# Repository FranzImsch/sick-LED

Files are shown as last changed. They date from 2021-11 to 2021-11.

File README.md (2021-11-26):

# Sick LED Driver

## [Schematic](https://franz.science/sick-LED/Schematic.pdf)
## [iBOM](https://franz.science/sick-LED/Hardware/KiCad-Files/bom/index.html)
  
**\*Work in progress\***

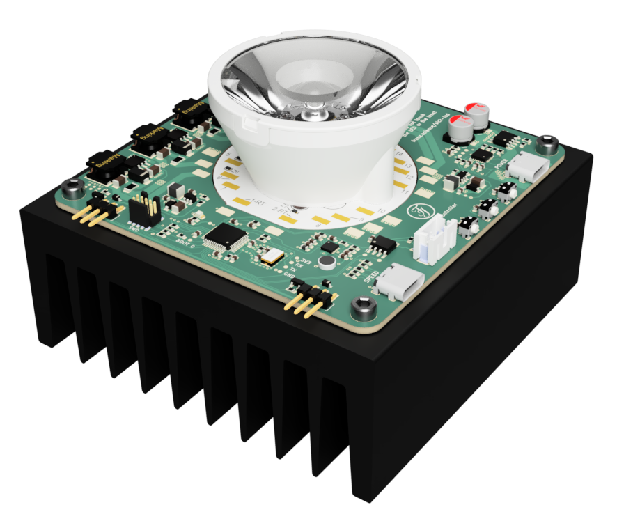
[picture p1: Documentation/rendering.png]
rendering


Six channel LED driver board that is built around the [LZ7-04-M2PD](https://www.osram.com/ecat/LED%20ENGIN%20LuxiGen%20LZ7-04M2PD/com/en/class_pim_web_catalog_103489/prd_pim_device_13582430/) on MCPCB from LED Engin.

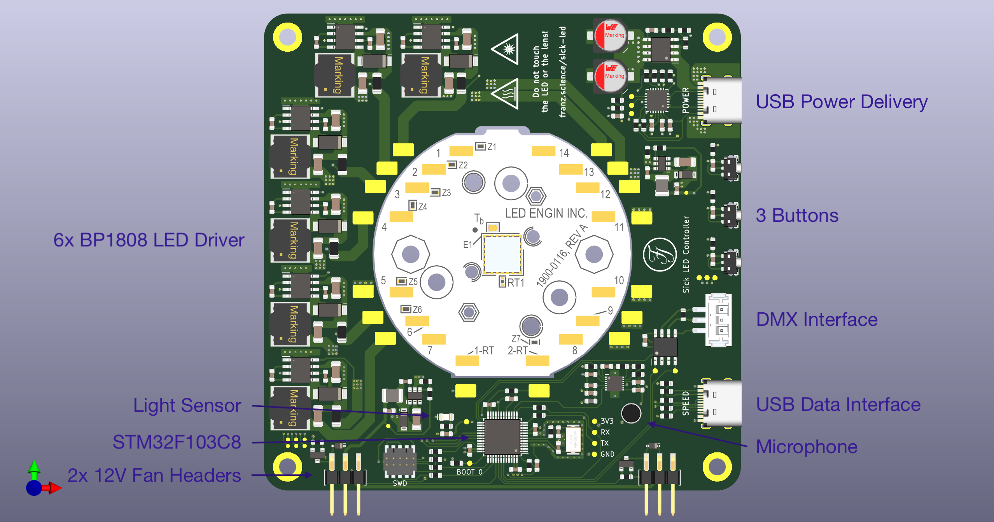
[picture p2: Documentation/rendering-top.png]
rendering

 It's a 60W LED with six colours, which can be used to do some adjustable white experiments due to the relatively full spectrum of the LED (at least compared to a normal RGB-LED): 

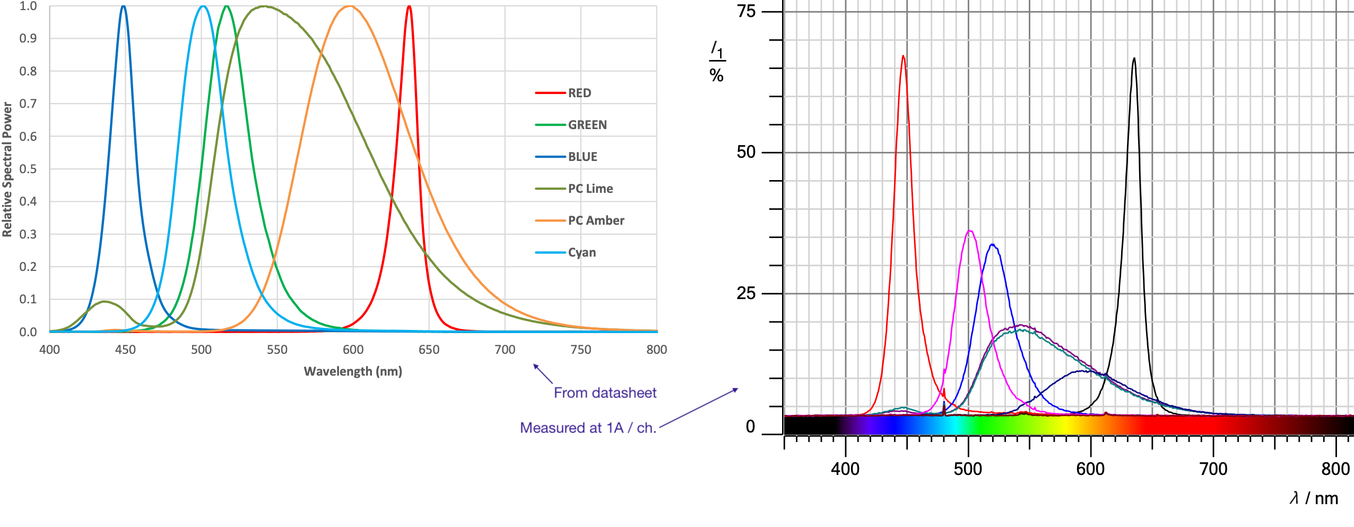
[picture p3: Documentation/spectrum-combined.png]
spectrum


The project's objective is not to build an LED that is as bright as possible but to create a dev board that makes it easy to study RGBALC LEDs. Thus, the board is powered via USB-PD and programmed with Arduino.

## Hardware
The PCB is mounted on a heatsink (100x100x40mm black anodised aluminium) using four M3 screws. Two 40mm fans could be attached to the heatsink and powered using the provided 2.54mm headers (the thermal characteristics of the whole design have not been tested yet).  

### Known (Hardware) Bugs
* Each PWM Channel had to be pulled down with a 4.7kΩ resistor.
* FAN1 pin (PB5, TIM3_CH2) cannot be used as PWM output when Hardware-I2C is initialised (Ch. 2.8.7 [ST Errata Sheet](https://www.st.com/resource/en/errata_sheet/es093-stm32f100x4-stm32f100x6-stm32f100x8-and-stm32f100xb-low-and-mediumdensity-value-line-device-limitations-stmicroelec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)).

### Fusion360 online viewer
https://a360.co/2VWAmD9

#### LED Driver (BP1808)
\*Docu\*

#### MCU
\*Docu\*

#### USB-C PD Chip
\*Docu\*

#### Buck Converter
\*Docu\*

#### RS-485 Transceiver
\*Docu\*

#### Microphone Amplifier
\*Docu\*

#### Light Sensor
\*Docu\*

## Software
To this point, the software is very basic. It allows the individual channels to be controlled from a computer (Linux or macOS) with [QLC+](https://www.qlcplus.org). It therefore pretends to be a nanoDMX device (No nanoDMX implementation in QLC+ on Windows, apparently).  
The buttons, microphone, light sensor and DMX interface are not yet implemented.  
The software should be rewritten using STM32Cube framework (in progress™).

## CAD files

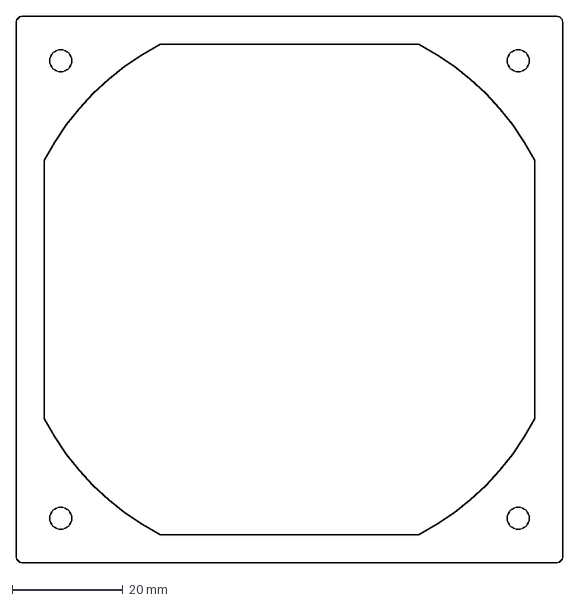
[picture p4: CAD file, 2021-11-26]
Hardware/fan-holder.dxf
98.5 x 98.5 mm

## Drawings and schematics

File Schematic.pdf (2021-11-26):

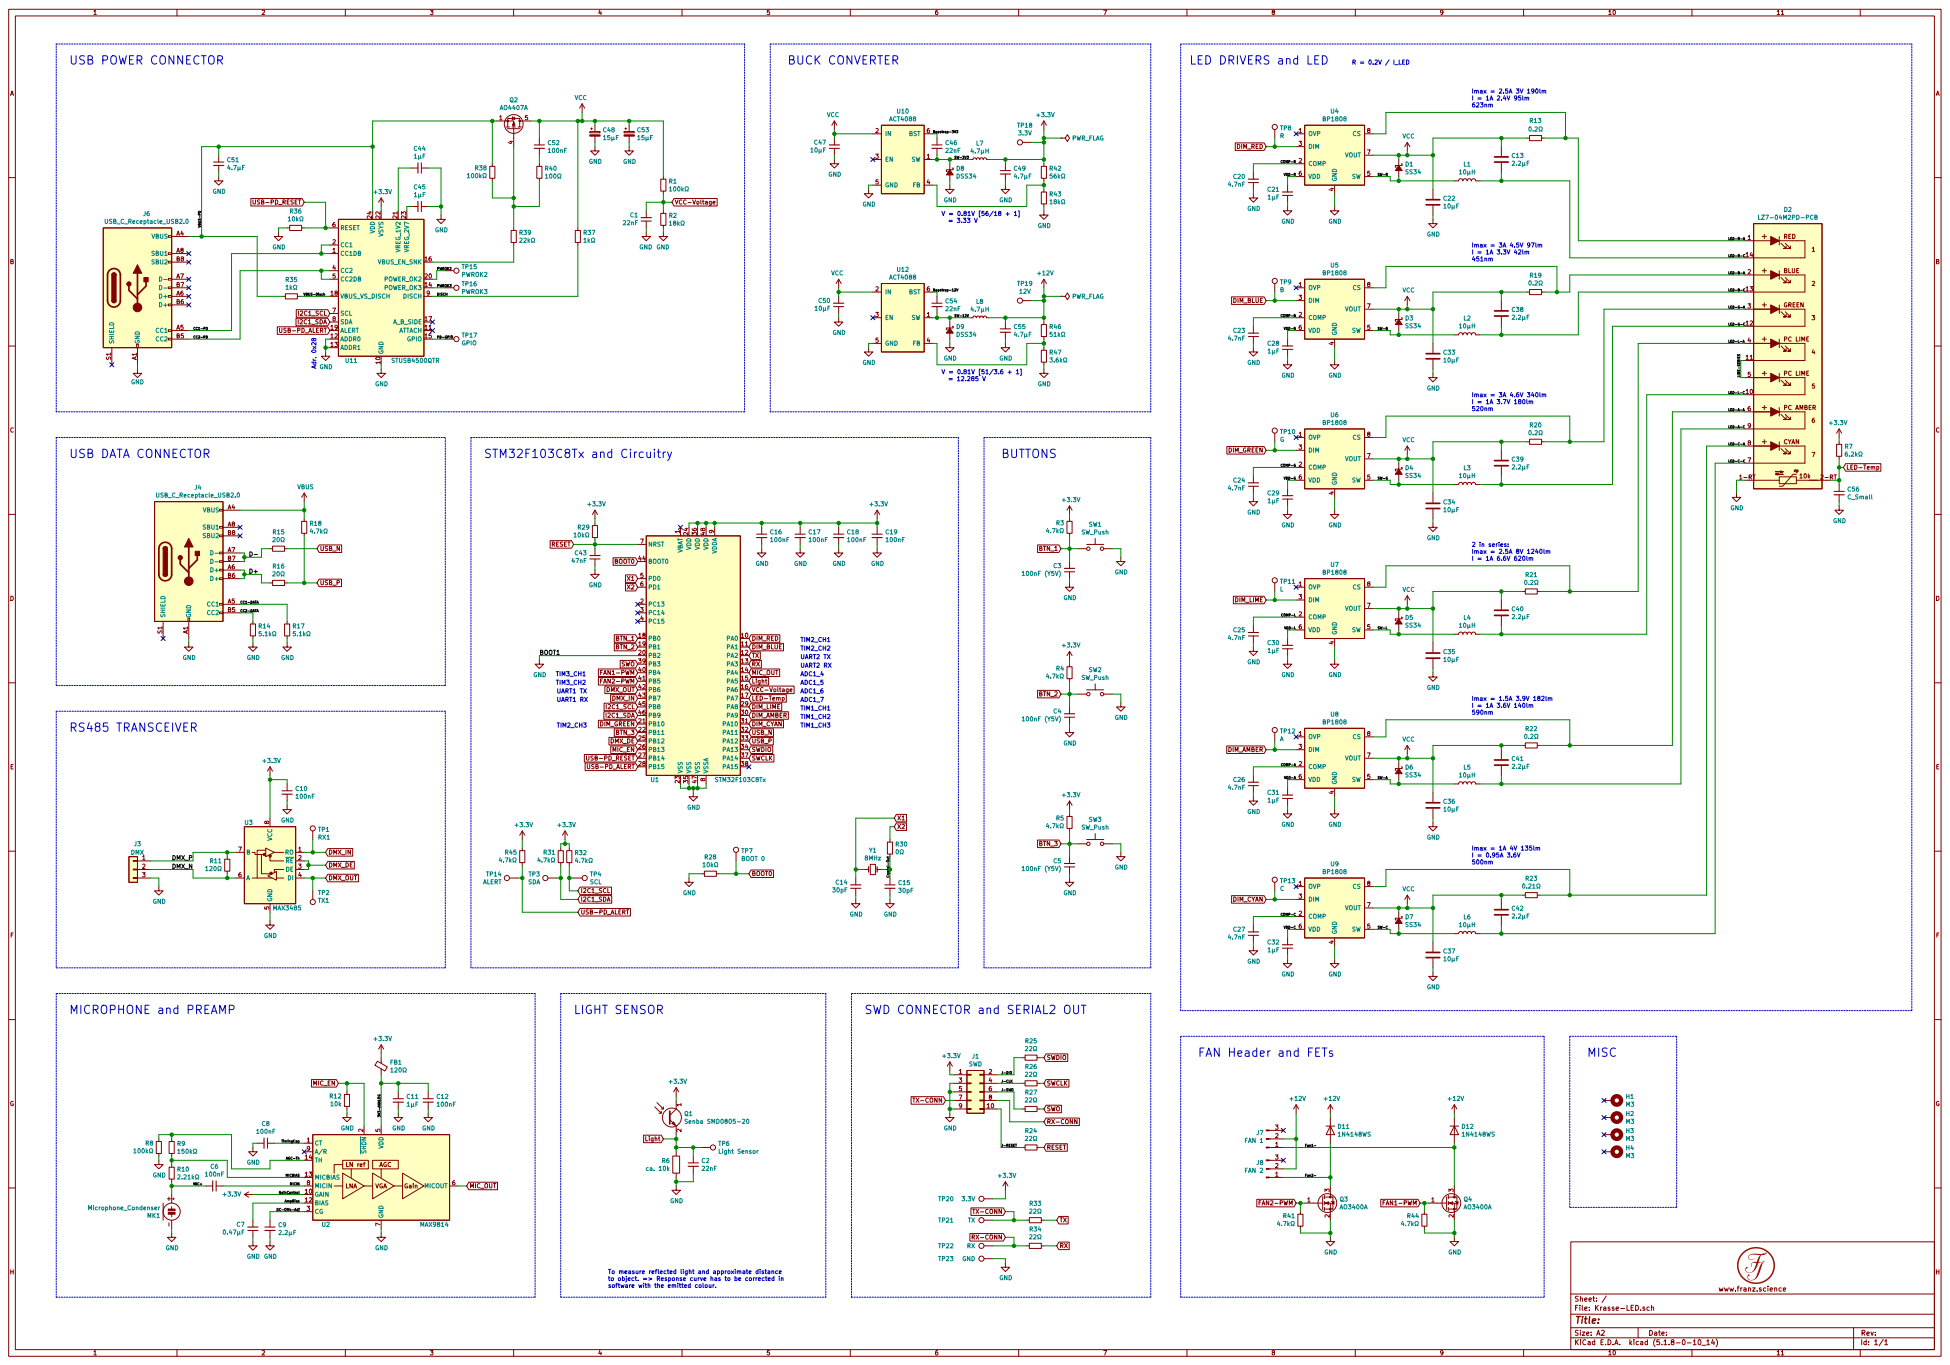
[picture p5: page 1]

LED DRIVERS and LED

7 MICIN 8 A/R 9 U2 MAX9814 + - MK1 Microphone_Condenser GND GND GND A1 VBUS A4 CC1 A5 D+ A6 D- A7 SBU1 A8 CC2 B5 D+ B6 D- B7 SBU2 B8 SHIELD S1

LED-L-A | 4

LED-A-A 6

9 VSS 23 VSS 35 VSS 47 VSSA U1 8STM32F103C8Tx +3.3V GND A1 VBUS A4 CC1 A5 D+ A6 D- A7 SBU1 A8 CC2 B5 D+ B6 D- B7 SBU2 B8 SHIELD S1

1 VDD 24 VDD 36 VDD 48 VDDA

To measure reflected light and approximate distance
to object. => Response curve has to be corrected in
software with the emitted colour.

Id: 1/1 Title: File: Krasse-LED.sch Sheet: /

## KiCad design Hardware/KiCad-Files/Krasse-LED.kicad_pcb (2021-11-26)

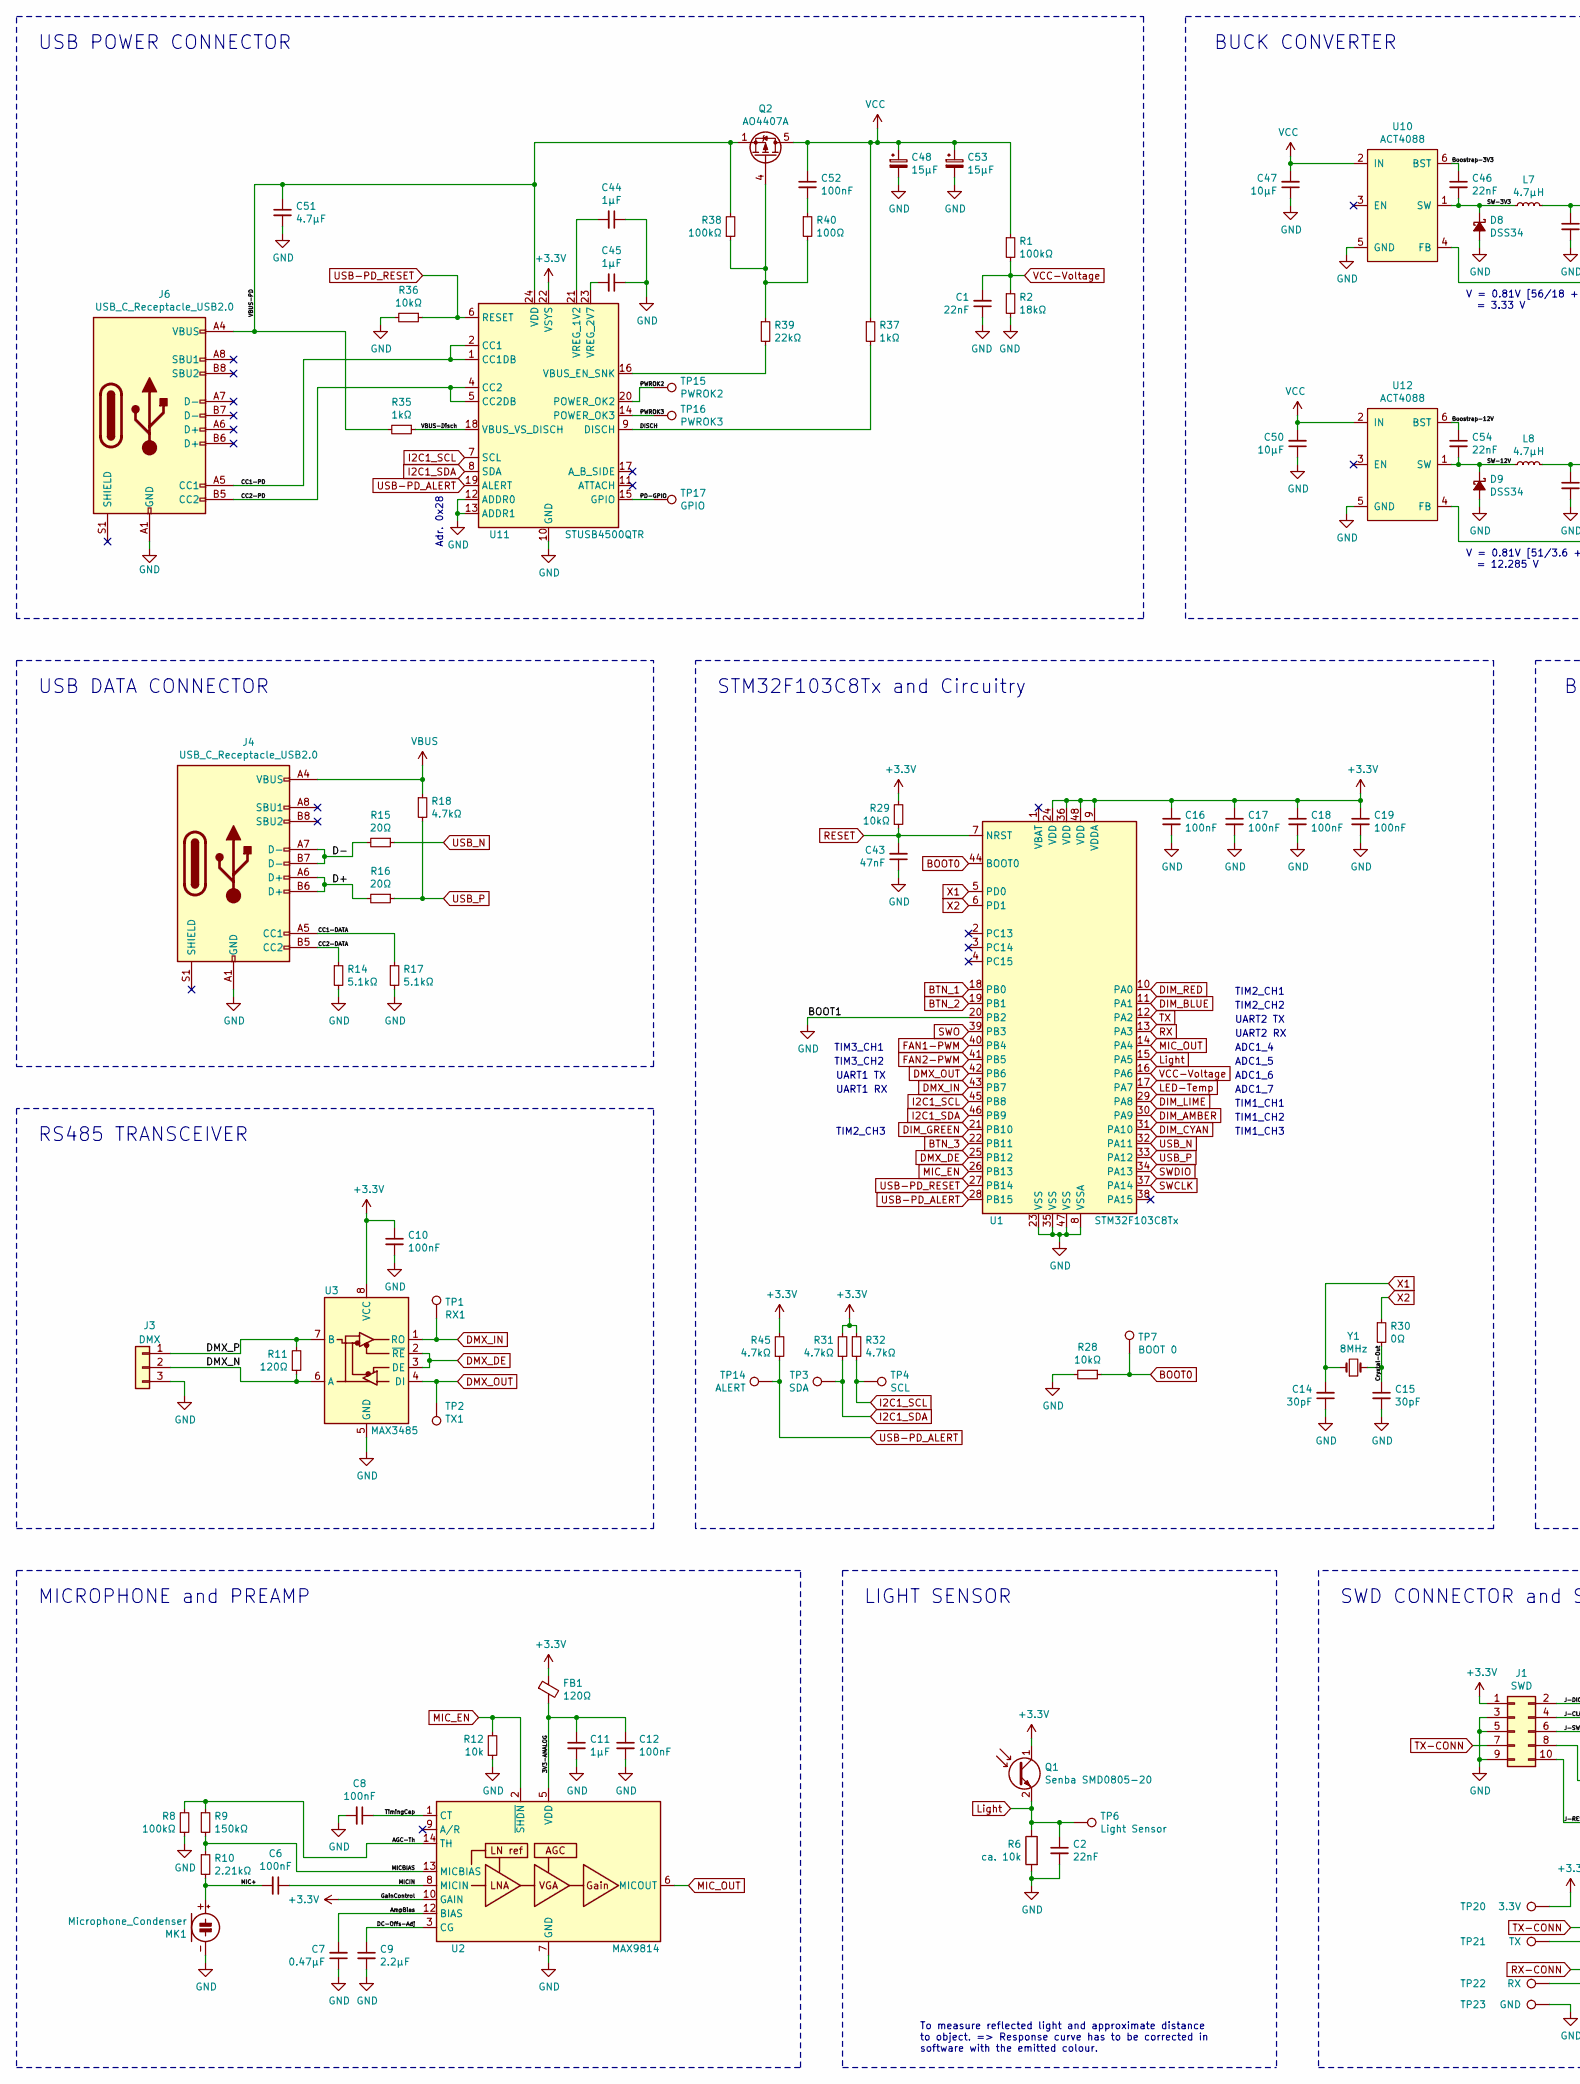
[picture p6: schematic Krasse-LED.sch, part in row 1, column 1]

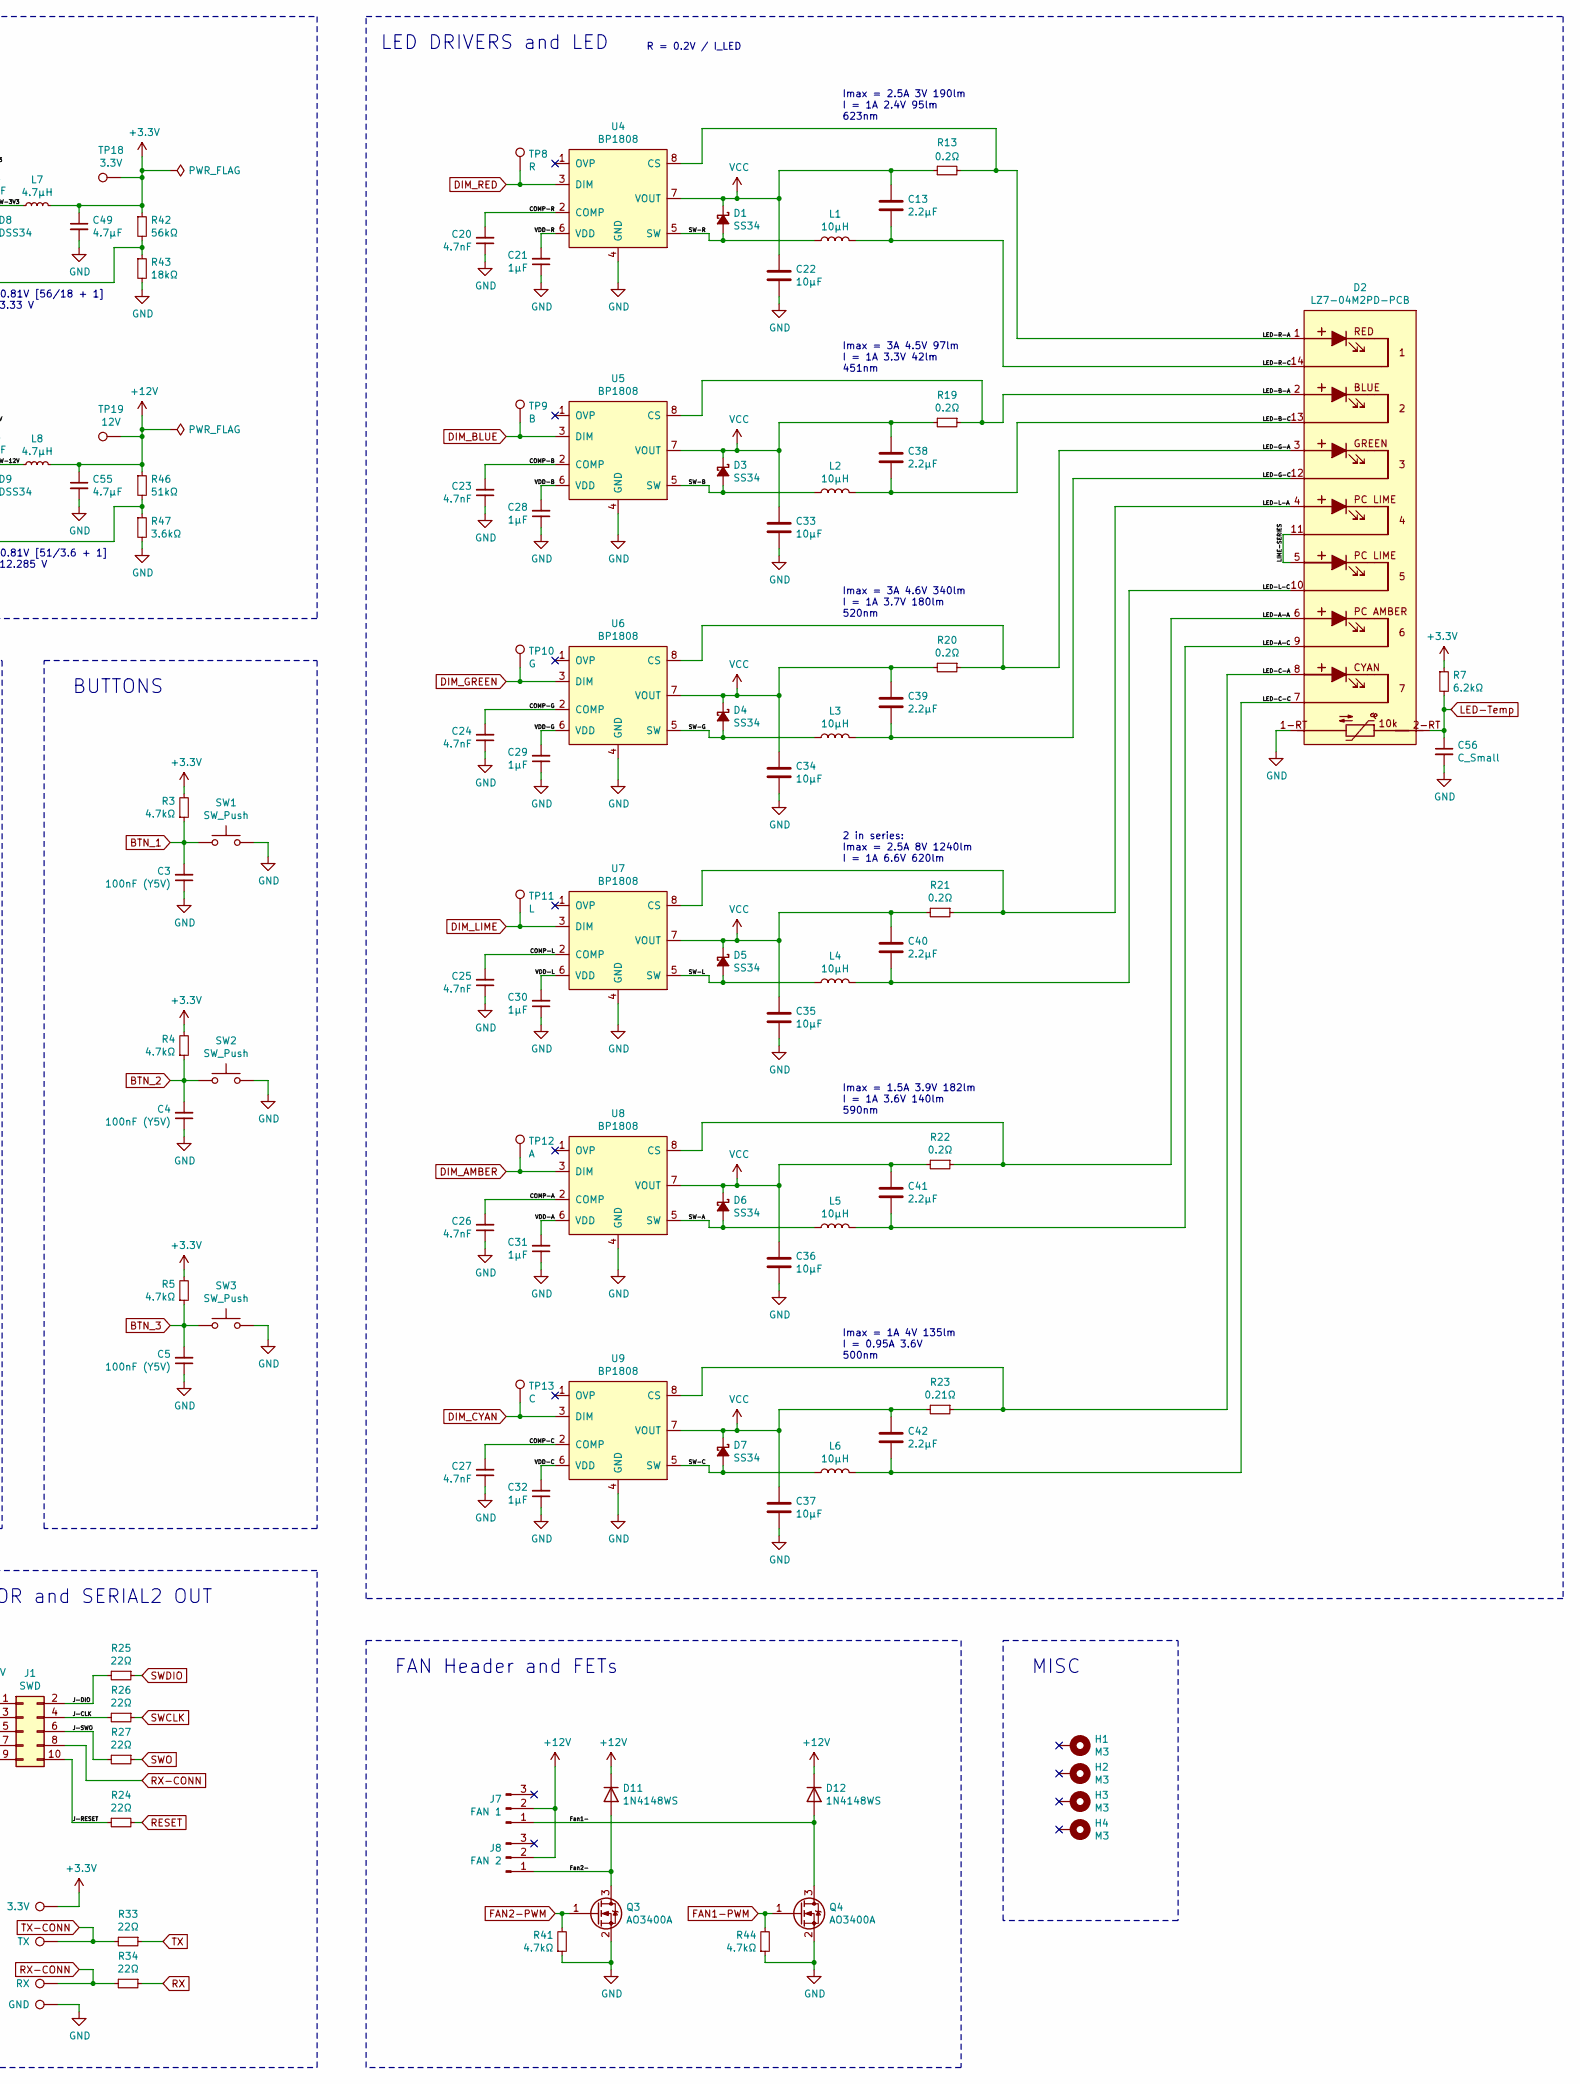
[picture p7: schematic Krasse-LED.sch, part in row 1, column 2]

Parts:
C1, C2, C46, C54: 22nF; C_0603_1608Metric
C3, C4, C5: 100nF (Y5V); C_0603_1608Metric
C6, C8, C10, C12, C16, C17, C18, C19, C52: 100nF; C_0603_1608Metric
C7: 0.47µF; C_0603_1608Metric
C9: 2.2µF; C_0603_1608Metric
C11, C21, C28, C29, C30, C31, C32, C44, C45: 1µF; C_0603_1608Metric
C13, C38, C39, C40, C41, C42: 2.2µF; C_1206_3216Metric
C14, C15: 30pF; C_0603_1608Metric
C20, C23, C24, C25, C26, C27: 4.7nF; C_0603_1608Metric
C22, C33, C34, C35, C36, C37, C47, C50: 10µF; C_1206_3216Metric
C43: 47nF; C_0603_1608Metric
C48, C53: 15µF; C_Elec_6.3x5.5_WE
C49, C51, C55: 4.7µF; C_0603_1608Metric
C56: C_Small; C_0603_1608Metric
D1, D3, D4, D5, D6, D7: SS34; D_SMA
D2: LZ7-04M2PD-PCB
D8, D9: DSS34; D_SOD-123
D11, D12: 1N4148WS; D_SOD-323
FB1: 120Ω; L_0603_1608Metric
H1, H2, H3, H4: M3; MountingHole_3.2mm_M3_DIN965_Pad
J1: SWD; PinHeader_2x05_P1.27mm_Vertical_SMD
J3: DMX; JST_PH_B3B-PH-SM4-TB_1x03-1MP_P2.00mm_Vertical
J4, J6: USB_C_Receptacle_USB2.0; USB_C_Receptacle_HRO_TYPE-C-31-M-12
J7: FAN 1; PinHeader_1x03_P2.54mm_Horizontal_SMD_Pin1Left
J8: FAN 2; PinHeader_1x03_P2.54mm_Horizontal_SMD_Pin1Left
L1, L2, L3, L4, L5, L6: 10µH; L_Chilisin_8040
L7, L8: 4.7µH; L_1210_3225Metric
MK1: Microphone_Condenser; B4013AM423-093
Q1: Senba SMD0805-20; LED_0805_2012Metric
Q2: AO4407A; SOIC-8_3.9x4.9mm_P1.27mm
Q3, Q4: AO3400A; SOT-23
R1, R8, R38: 100kΩ; R_0603_1608Metric
R2, R43: 18kΩ; R_0603_1608Metric
R3, R4, R5, R18, R31, R32, R41, R44, R45: 4.7kΩ; R_0603_1608Metric
R6: ca. 10k; R_0603_1608Metric
R7: 6.2kΩ; R_0603_1608Metric
R9: 150kΩ; R_0603_1608Metric
R10: 2.21kΩ; R_0603_1608Metric
R11: 120Ω; R_0603_1608Metric
R12: 10k; R_0603_1608Metric
R13, R19, R20, R21, R22: 0.2Ω; R_1206_3216Metric
R14, R17: 5.1kΩ; R_0603_1608Metric
R15, R16: 20Ω; R_0603_1608Metric
R23: 0.21Ω; R_1206_3216Metric
R24, R25, R26, R27, R33, R34: 22Ω; R_0603_1608Metric
R28, R29, R36: 10kΩ; R_0603_1608Metric
R30: 0Ω; R_0603_1608Metric
R35, R37: 1kΩ; R_0603_1608Metric
R39: 22kΩ; R_0603_1608Metric
R40: 100Ω; R_0603_1608Metric
R42: 56kΩ; R_0603_1608Metric
R46: 51kΩ; R_0603_1608Metric
R47: 3.6kΩ; R_0603_1608Metric
SW1, SW2, SW3: SW_Push; SW_Push_1P1T-MP_NO_Horizontal_Alps_SKRTLAE010
TP1: RX1; TestPoint_Pad_D1.0mm
TP2: TX1; TestPoint_Pad_D1.0mm
TP3: SDA; TestPoint_Pad_D1.0mm
TP4: SCL; TestPoint_Pad_D1.0mm
TP6: Light Sensor; TestPoint_Pad_D1.0mm
TP7: BOOT 0; TestPoint_Pad_D1.0mm
TP8: R; TestPoint_Pad_D0.8mm
TP9: B; TestPoint_Pad_D0.8mm
TP10: G; TestPoint_Pad_D0.8mm
TP11: L; TestPoint_Pad_D0.8mm
TP12: A; TestPoint_Pad_D0.8mm
TP13: C; TestPoint_Pad_D0.8mm
TP14: ALERT; TestPoint_Pad_D1.0mm
TP15: PWROK2; TestPoint_Pad_D1.0mm
TP16: PWROK3; TestPoint_Pad_D1.0mm
TP17: GPIO; TestPoint_Pad_D1.0mm
TP18: 3.3V; TestPoint_Pad_D0.8mm
TP19: 12V; TestPoint_Pad_D0.8mm
TP20: 3.3V; TestPoint_Pad_D1.0mm
TP21: TX; TestPoint_Pad_D1.0mm
TP22: RX; TestPoint_Pad_D1.0mm
TP23: GND; TestPoint_Pad_D1.0mm
U1: STM32F103C8Tx; LQFP-48_7x7mm_P0.5mm
U2: MAX9814; DFN-14-1EP_3x3mm_P0.4mm_EP1.78x2.35mm
U3: MAX3485; SOP-8_3.9x4.9mm_P1.27mm
U4, U5, U6, U7, U8, U9: BP1808; Texas_HSOP-8-1EP_3.9x4.9mm_P1.27mm
U10, U12: ACT4088; SOT-23-6
U11: STUSB4500QTR; QFN-24-1EP_4x4mm_P0.5mm_EP2.7x2.7mm
Y1: 8MHz; Crystal_SMD_5032-2Pin_5.0x3.2mm

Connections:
+3V3: C10.1, C16.1, C17.1, C18.1, C19.1, C49.1, FB1.1, J1.1, L7.2, Q1.1 (C), R3.2, R4.2, R5.2, R7.1, R29.2, R31.2, R32.1, R42.1, R45.2, TP18.1, TP20.1, U1.9 (VDDA), U1.24 (VDD), U1.36 (VDD), U1.48 (VDD), U2.10 (GAIN), U3.8 (VCC), U11.22 (VSYS)
+12V: C55.1, D11.1 (K), D12.1 (K), J7.2, J8.2, L8.2, R46.1, TP19.1
/3V3-ANALOG: C11.1, C12.1, FB1.2, U2.5 (VDD)
/AGC-Th: R8.2, R9.1, U2.14 (TH)
/AmpBias: C7.2, U2.12 (BIAS)
/Boostrap-3V3: C46.1, U10.6 (BST)
/Boostrap-12V: C54.1, U12.6 (BST)
/CC1-DATA: J4.A5 (CC1), R17.1
/CC1-PD: J6.A5 (CC1), U11.1 (CC1DB), U11.2 (CC1)
/CC2-DATA: J4.B5 (CC2), R14.1
/CC2-PD: J6.B5 (CC2), U11.4 (CC2), U11.5 (CC2DB)
/COMP-A: C26.2, U8.2 (COMP)
/COMP-B: C23.2, U5.2 (COMP)
/COMP-C: C27.2, U9.2 (COMP)
/COMP-G: C24.2, U6.2 (COMP)
/COMP-L: C25.2, U7.2 (COMP)
/COMP-R: C20.2, U4.2 (COMP)
/Crystal-Out: C15.1, R30.2, Y1.2
/D+: J4.A6 (D+), J4.B6 (D+), R16.2
/D-: J4.A7 (D-), J4.B7 (D-), R15.2
/DC-Offs-Adj: C9.1, U2.3 (CG)
/DISCH: R37.2, U11.9 (DISCH)
/DMX_N: J3.2, R11.1, U3.6 (A)
/DMX_P: J3.1, R11.2, U3.7 (B)
/Fan1-: D12.2 (A), J7.1, Q4.3 (D)
/Fan2-: D11.2 (A), J8.1, Q3.3 (D)
/J-CLK: J1.4, R26.2
/J-DIO: J1.2, R25.2
/J-RESET: J1.10, R24.1
/J-SWO: J1.6, R27.2
/LED-A-A: D2.6 (A-A), R22.1, U8.8 (CS)
/LED-A-C: C41.2, D2.9 (A-C), L5.2
/LED-B-A: D2.2 (B-A), R19.1, U5.8 (CS)
/LED-B-C: C38.2, D2.13 (B-C), L2.2
/LED-C-A: D2.8 (C-A), R23.1, U9.8 (CS)
/LED-C-C: C42.2, D2.7 (C-C), L6.2
/LED-G-A: D2.3 (G-A), R20.1, U6.8 (CS)
/LED-G-C: C39.2, D2.12 (G-C), L3.2
/LED-L-A: D2.4 (L-A), R21.1, U7.8 (CS)
/LED-L-C: C40.2, D2.10 (L-C), L4.2
/LED-R-A: D2.1 (R-A), R13.2, U4.8 (CS)
/LED-R-C: C13.2, D2.14 (R-C), L1.2
/LIME-SERIES: D2.5 (L-A), D2.11 (L-C)
/MIC+: C6.2, MK1.+, R10.2
/MICBIAS: R9.2, R10.1, U2.13 (MICBIAS)
/MICIN: C6.1, U2.8 (MICIN)
/PD-GPIO: TP17.1, U11.15 (GPIO)
/PWROK2: TP15.1, U11.20 (POWER_OK2)
/PWROK3: TP16.1, U11.14 (POWER_OK3)
/SW-3V3: C46.2, D8.1 (K), L7.1, U10.1 (SW)
/SW-12V: C54.2, D9.1 (K), L8.1, U12.1 (SW)
/SW-A: D6.2 (A), L5.1, U8.5 (SW)
/SW-B: D3.2 (A), L2.1, U5.5 (SW)
/SW-C: D7.2 (A), L6.1, U9.5 (SW)
/SW-G: D4.2 (A), L3.1, U6.5 (SW)
/SW-L: D5.2 (A), L4.1, U7.5 (SW)
/SW-R: D1.2 (A), L1.1, U4.5 (SW)
/TimingCap: C8.1, U2.1 (CT)
/VBUS-Disch: R35.1, U11.18 (VBUS_VS_DISCH)
/VBUS-PD: C51.1, J6.A4 (VBUS), J6.A9 (VBUS), J6.B4 (VBUS), J6.B9 (VBUS), Q2.1 (S), Q2.2 (S), Q2.3 (S), R35.2, R38.2, U11.24 (VDD)
/VDD-A: C31.2, U8.6 (VDD)
/VDD-B: C28.2, U5.6 (VDD)
/VDD-C: C32.2, U9.6 (VDD)
/VDD-G: C29.2, U6.6 (VDD)
/VDD-L: C30.2, U7.6 (VDD)
/VDD-R: C21.2, U4.6 (VDD)
BOOT0: R28.1, TP7.1, U1.44 (BOOT0)
BTN_1: C3.2, R3.1, SW1.1, U1.18 (PB0)
BTN_2: C4.2, R4.1, SW2.1, U1.19 (PB1)
BTN_3: C5.2, R5.1, SW3.1, U1.22 (PB11)
DIM_AMBER: TP12.1, U1.30 (PA9), U8.3 (DIM)
DIM_BLUE: TP9.1, U1.11 (PA1), U5.3 (DIM)
DIM_CYAN: TP13.1, U1.31 (PA10), U9.3 (DIM)
DIM_GREEN: TP10.1, U1.21 (PB10), U6.3 (DIM)
DIM_LIME: TP11.1, U1.29 (PA8), U7.3 (DIM)
DIM_RED: TP8.1, U1.10 (PA0), U4.3 (DIM)
DMX_DE: U1.25 (PB12), U3.2 (~RE), U3.3 (DE)
DMX_IN: TP1.1, U1.43 (PB7), U3.1 (RO)
DMX_OUT: TP2.1, U1.42 (PB6), U3.4 (DI)
FAN1-PWM: Q4.1 (G), R44.2, U1.40 (PB4)
FAN2-PWM: Q3.1 (G), R41.2, U1.41 (PB5)
GND: C1.1, C2.2, C3.1, C4.1, C5.1, C7.1, C8.2, C9.2, C10.2, C11.2, C12.2, C14.1, C15.2, C16.2, C17.2, C18.2, C19.2, C20.1, C21.1, C22.2, C23.1, C24.1, C25.1, C26.1, C27.1, C28.1, C29.1, C30.1, C31.1, C32.1, C33.2, C34.2, C35.2, C36.2, C37.2, C43.1, C44.1, C45.1, C47.1, C48.-, C49.2, C50.1, C51.2, C53.-, C55.2, C56.2, D2.1-RT, D8.2 (A), D9.2 (A), J1.3, J1.5, J1.9, J3.3, J4.A1 (GND), J4.A12 (GND), J4.B1 (GND), J4.B12 (GND), J6.A1 (GND), J6.A12 (GND), J6.B1 (GND), J6.B12 (GND), MK1.-, Q3.2 (S), Q4.2 (S), R2.2, R6.2, R8.1, R12.1, R14.2, R17.2, R28.2, R36.2, R41.1, R43.2, R44.1, R47.2, SW1.2, SW2.2, SW3.2, TP23.1, U1.8 (VSSA), U1.20 (PB2), U1.23 (VSS), U1.35 (VSS), U1.47 (VSS), U2.4 (GND), U2.7 (GND), U2.11 (GND), U2.15 (GND), U3.5 (GND), U4.4 (GND), U4.9 (PAD), U5.4 (GND), U5.9 (PAD), U6.4 (GND), U6.9 (PAD), U7.4 (GND), U7.9 (PAD), U8.4 (GND), U8.9 (PAD), U9.4 (GND), U9.9 (PAD), U10.5 (GND), U11.10 (GND), U11.12 (ADDR0), U11.13 (ADDR1), U11.25 (GND), U12.5 (GND)
I2C1_SCL: R32.2, TP4.1, U1.45 (PB8), U11.7 (SCL)
I2C1_SDA: R31.1, TP3.1, U1.46 (PB9), U11.8 (SDA)
LED-Temp: C56.1, D2.2-RT, R7.2, U1.17 (PA7)
Light: C2.1, Q1.2 (E), R6.1, TP6.1, U1.15 (PA5)
MIC_EN: R12.2, U1.26 (PB13), U2.2 (~SHDN)
MIC_OUT: U1.14 (PA4), U2.6 (MICOUT)
unnamed: C44.2, U11.21 (VREG_1V2)
unnamed: C45.2, U11.23 (VREG_2V7)
unnamed: C52.2, R40.1
unnamed: Q2.4 (G), R38.1, R39.1, R40.2
unnamed: R39.2, U11.16 (VBUS_EN_SNK)
unnamed: R42.2, R43.1, U10.4 (FB)
unnamed: R46.2, R47.1, U12.4 (FB)
RESET: C43.2, R24.2, R29.1, U1.7 (NRST)
RX: R34.1, U1.13 (PA3)
RX-CONN: J1.8, R34.2, TP22.1
SWCLK: R26.1, U1.37 (PA14)
SWDIO: R25.1, U1.34 (PA13)
SWO: R27.1, U1.39 (PB3)
TX: R33.1, U1.12 (PA2)
TX-CONN: J1.7, R33.2, TP21.1
USB-PD_ALERT: R45.1, TP14.1, U1.28 (PB15), U11.19 (ALERT)
USB-PD_RESET: R36.1, U1.27 (PB14), U11.6 (RESET)
USB_N: R15.1, U1.32 (PA11)
USB_P: R16.1, R18.2, U1.33 (PA12)
VBUS: J4.A4 (VBUS), J4.A9 (VBUS), J4.B4 (VBUS), J4.B9 (VBUS), R18.1
VCC: C13.1, C22.1, C33.1, C34.1, C35.1, C36.1, C37.1, C38.1, C39.1, C40.1, C41.1, C42.1, C47.2, C48.+, C50.2, C52.1, C53.+, D1.1 (K), D3.1 (K), D4.1 (K), D5.1 (K), D6.1 (K), D7.1 (K), Q2.5 (D), Q2.6 (D), Q2.7 (D), Q2.8 (D), R1.1, R13.1, R19.2, R20.2, R21.2, R22.2, R23.2, R37.1, U4.7 (VOUT), U5.7 (VOUT), U6.7 (VOUT), U7.7 (VOUT), U8.7 (VOUT), U9.7 (VOUT), U10.2 (IN), U12.2 (IN)
VCC-Voltage: C1.2, R1.2, R2.1, U1.16 (PA6)
X1: C14.2, U1.5 (PD0), Y1.1
X2: R30.1, U1.6 (PD1)

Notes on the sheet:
To measure reflected light and approximate distance to object. => Response curve has to be corrected in software with the emitted colour.
MICROPHONE and PREAMP
LIGHT SENSOR
BUTTONS
UART1 TX
UART1 RX
ADC1_4
ADC1_5
ADC1_6
TIM1_CH1
TIM1_CH2
TIM1_CH3
TIM2_CH1
TIM2_CH2
TIM2_CH3
ADC1_7
R = 0.2V / I_LED
LED DRIVERS and LED
STM32F103C8Tx and Circuitry
RS485 TRANSCEIVER
USB DATA CONNECTOR
UART2 TX
UART2 RX
SWD CONNECTOR and SERIAL2 OUT
TIM3_CH1
TIM3_CH2
Imax = 2.5A 3V 190lm I = 1A 2.4V 95lm 623nm
Imax = 3A 4.5V 97lm I = 1A 3.3V 42lm 451nm
Imax = 3A 4.6V 340lm I = 1A 3.7V 180lm 520nm
2 in series: Imax = 2.5A 8V 1240lm I = 1A 6.6V 620lm
Imax = 1.5A 3.9V 182lm I = 1A 3.6V 140lm 590nm
Imax = 1A 4V 135lm I = 0.95A 3.6V 500nm
BUCK CONVERTER
Adr. 0x28
USB POWER CONNECTOR
FAN Header and FETs
MISC
V = 0.81V [56/18 + 1] = 3.33 V
V = 0.81V [51/3.6 + 1] = 12.285 V

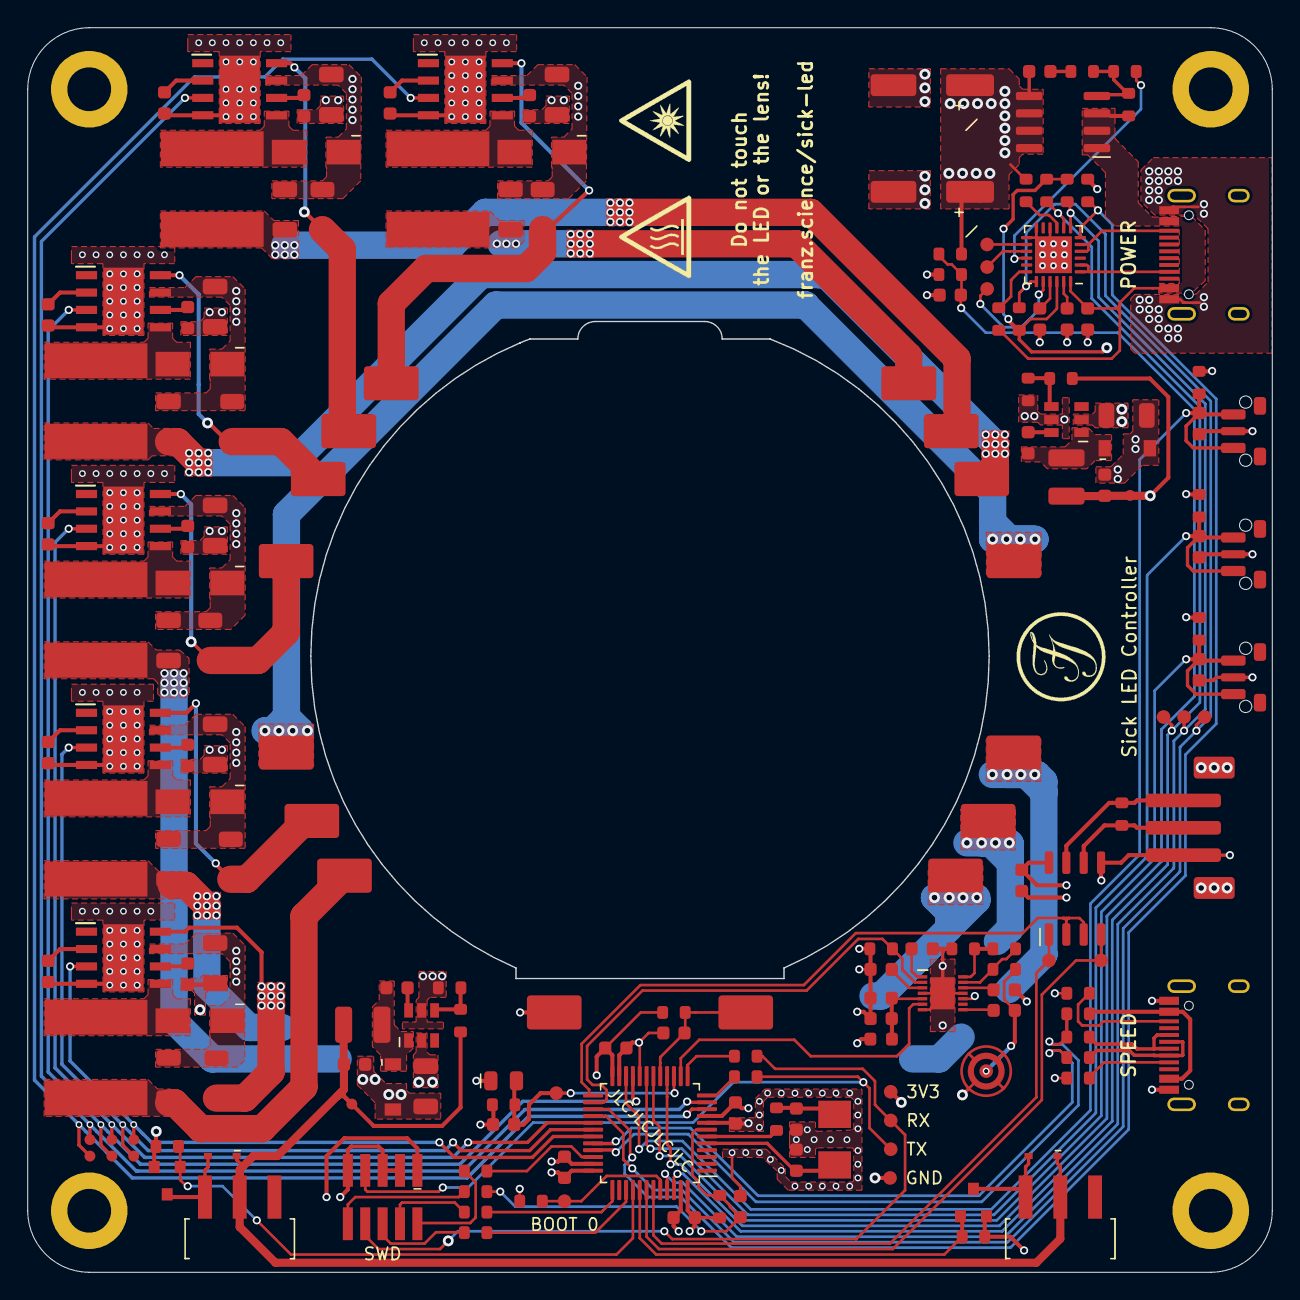
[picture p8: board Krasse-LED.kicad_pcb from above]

Board: 4 copper layers, 91.0 x 91.0 mm, 176 parts (0 on the bottom side), 112 nets.

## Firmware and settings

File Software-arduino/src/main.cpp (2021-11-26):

#include <Arduino.h>

#include "globals.h"
#include "safety.h"
#include "LED.h"
#include "nanoDMX.h"
#include "USB-PD.h"

HardwareSerial Serial2(Serial2_RX, Serial2_TX);

long lastmil = 0;

void setup()
{
#ifdef DEBUG
  Serial2.begin(115200);
#endif
  DEBUG_PRINT("Hello c:");

  USBPDinit(); // i2c / timer issue
  LEDinit();
  nanoDMXinit();
  safetyinit();
}

void loop()
{
  long now = millis();
  if (now - lastmil >= 2500)
  {
    lastmil = now;
    safetyRoutine();
  }

  receiveDMXviaUSB();
}

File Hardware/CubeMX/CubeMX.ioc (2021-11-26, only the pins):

Mcu.UserName=STM32F103C8Tx
PA0-WKUP.Signal=S_TIM2_CH1_ETR
PA1.Signal=S_TIM2_CH2
PA10.Signal=S_TIM1_CH3
PA11.Signal=USB_DM
PA12.Signal=USB_DP
PA13.Signal=SYS_JTMS-SWDIO
PA14.Signal=SYS_JTCK-SWCLK
PA2.Signal=USART2_TX
PA3.Signal=USART2_RX
PA4.Signal=ADCx_IN4
PA5.Signal=ADCx_IN5
PA6.Signal=ADCx_IN6
PA7.Signal=ADCx_IN7
PA8.Signal=S_TIM1_CH1
PA9.Signal=S_TIM1_CH2
PB10.Signal=S_TIM2_CH3
PB11.Signal=S_TIM2_CH4
PB3.Signal=SYS_JTDO-TRACESWO
PB4.Signal=S_TIM3_CH1
PB5.Signal=S_TIM3_CH2
PB6.Signal=USART1_TX
PB7.Signal=USART1_RX
PB8.Signal=I2C1_SCL
PB9.Signal=I2C1_SDA
PD0-OSC_IN.Signal=RCC_OSC_IN
PD1-OSC_OUT.Signal=RCC_OSC_OUT
